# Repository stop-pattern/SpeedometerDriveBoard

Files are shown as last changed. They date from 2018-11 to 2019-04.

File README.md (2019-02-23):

SpeedometerDriveBoard
===

## table of contents
- [日本語版](#Japanese)[](\readme_jp.md)
- [English](#English)
  - [Requirement](#Requirement)
  - [Installation](#Installation)
    - [board](#board)
    - [code](#code)
  - [Licence](#Licence)
  - [Author](#Author)

---

## Japanese
このリポジトリ内の創造物は、[BIDSid_SerCon](https://github.com/TetsuOtter/BIDSid_SerCon/)を使用する前提で設計されています。  
基板は5000円以下/枚で生産できますが、現在製造中につき値段の詳細については分かりかねます。(分かり次第追記予定  
日本語版は工事中ですのでお手数ですが下記英語版をご覧いただきますよう...

---

## English
This Repository is designed on the premise of using [__BIDSid_SerCon__](https://github.com/TetsuOtter/BIDSid_SerCon/).  
This is for original board on esp32 that created and designed by stop_pattern.  
This board can be produced at less than 5000JPY / piece.  
But do not know details of the price because it is currently under manufacturing.  
(Scheduled to be appended as soon as it is known)  

### Requirement
using:
[BIDSid_SerCon](https://github.com/TetsuOtter/BIDSid_SerCon/).  
supported:
[Bve trainsim](http://bvets.net/)  
support __Bve trainsim__, but the supported version _5.7_ or newer.  
__Bve trainsim__ spported only _Windows Vista_ or _newer_, so support only _Windows Vista_ or _newer_ too.  

### Usage
Change the settings, in the firmware source code according to your own environment.  
write firmware to esp32 through __Arduino IDE__.  

### Installation
#### board:
1. Request PCB service company to manufacture circuit board.  
2. Test manufactured board and Implemented parts.  
#### code:
1. write firmware to esp32 through __Arduino IDE__.  
2. setup [__Bve trainsim__](http://bvets.net/en/download/)  
3. Introduce [__BIDSid_SerCon__](https://github.com/TetsuOtter/BIDSid_SerCon/) into __Bve trainsim__.  

### Licence
board:
[GPLv3](https://www.gnu.org/licenses/gpl-3.0.html)  
code:
[MIT](https://github.com/tcnksm/tool/blob/master/LICENCE)  

### Author
[stop_pattern](https://github.com/stop-pattern)

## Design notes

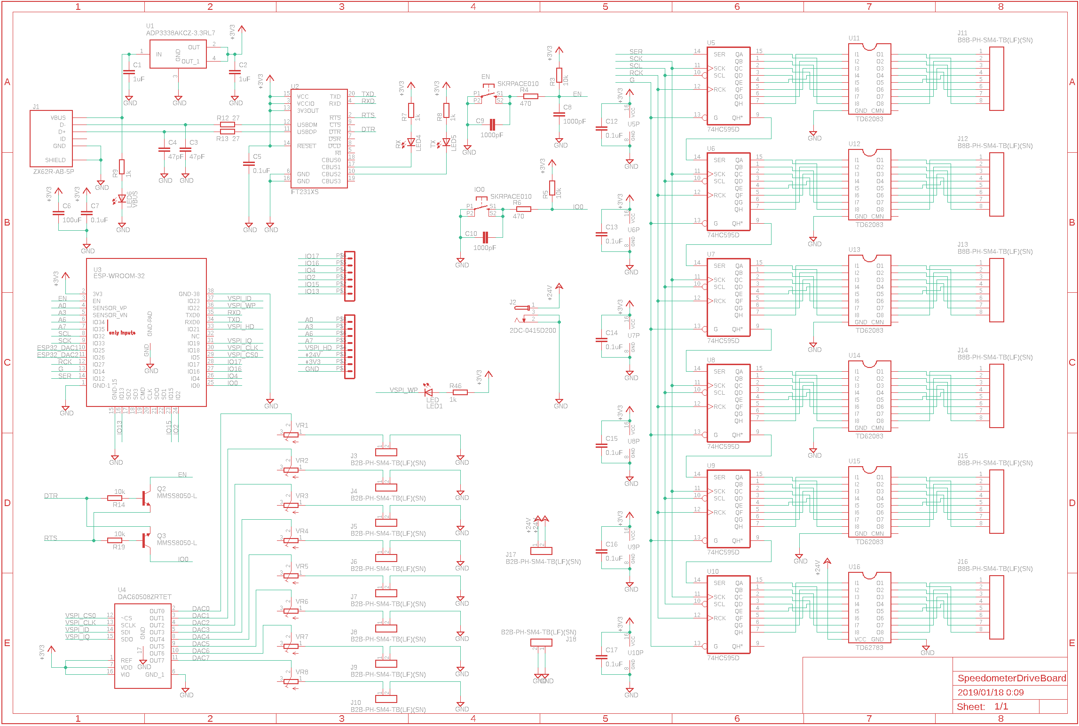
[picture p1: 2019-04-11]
board/sch.png

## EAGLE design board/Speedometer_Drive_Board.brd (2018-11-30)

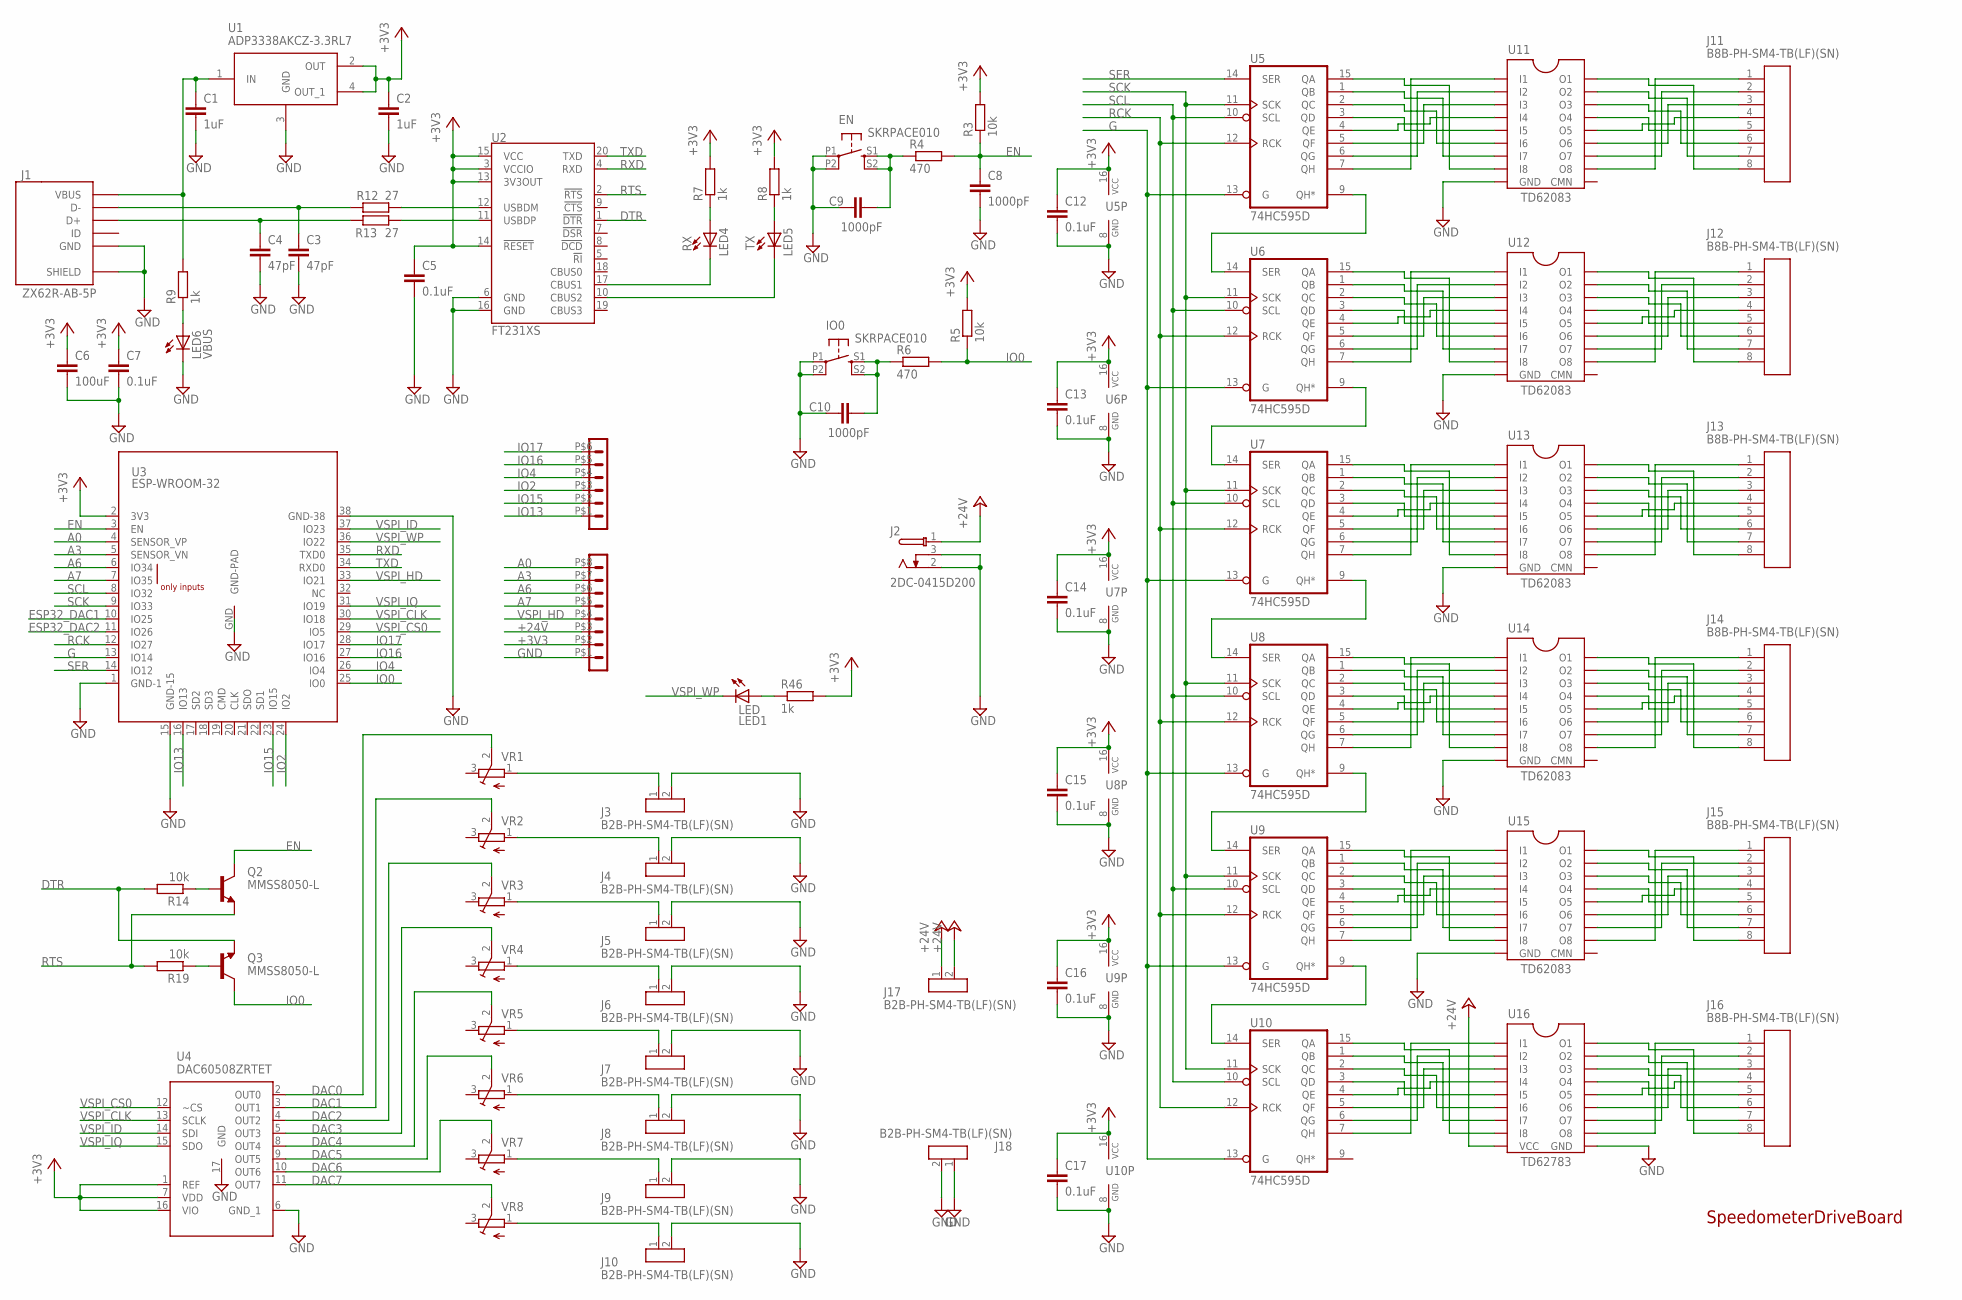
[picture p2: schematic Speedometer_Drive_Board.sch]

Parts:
C1, C2: 1uF; C0603
C3, C4: 47pF; C0603
C5, C7, C12, C13, C14, C15, C16, C17: 0.1uF; C0603
C6: 100uF; C1210
C8, C9, C10: 1000pF; C0603
EN: SKRPACE010
IO0: SKRPACE010
J1: ZX62R-AB-5P; ZX62R-B-5PA
J2: 2DC-0415D200
J3, J4, J5, J6, J7, J8, J9, J10, J17, J18: B2B-PH-SM4-TB(LF)(SN); SAMACSYS_PARTS_B2B-PH-SM4-TB
J11, J12, J13, J14, J15, J16: B8B-PH-SM4-TB(LF)(SN); SAMACSYS_PARTS_B8B-PH-SM4-TB
J19: PIN_HEADER_MALE_1X06_06P
J20: PIN_HEADER_MALE_1X08_08P
LED: LED1; CHIPLED_0603
LED4: RX; CHIPLED_0603
LED5: TX; CHIPLED_0603
LED6: VBUS; CHIPLED_0603
Q2, Q3: MMSS8050-L; SOT23
R3, R5, R14, R19: 10k; R0603
R4, R6: 470; R0603
R7, R8, R9, R46: 1k; R0603
R12, R13: 27; R0603
U1: ADP3338AKCZ-3.3RL7; SOT230P700X180-4N
U2: FT231XS; SSOP20_L
U3: ESP-WROOM-32
U4: DAC60508ZRTET; SAMACSYS_PARTS_QFN50P300X300X80-17N
U5, U6, U7, U8, U9, U10: 74HC595D; SO16
U11, U12, U13, U14, U15: TD62083; SO18
U16: TD62783; SO18
VR1, VR2, VR3, VR4, VR5, VR6, VR7, VR8: TRIM_EU-SM-42/43W; SM-42/43W

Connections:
+3V3: C2.1, C5.1, C6.1, C7.1, C12.1, C13.1, C14.1, C15.1, C16.1, C17.1, J20.P$2 (2), R3.2, R5.2, R7.2, R8.2, R46.2, U1.2 (OUT), U1.4 (OUT_1), U2.3 (VCCIO), U2.13 (3V3OUT), U2.14 (!RESET), U2.15 (VCC), U3.2 (3V3), U4.1 (REF), U4.7 (VDD), U4.16 (VIO), U5.16 (VCC), U6.16 (VCC), U7.16 (VCC), U8.16 (VCC), U9.16 (VCC), U10.16 (VCC)
+24V: J2.1, J17.1, J17.2, J20.P$3 (3), U16.9 (VCC)
A0: J20.P$8 (8), U3.4 (SENSOR_VP)
A3: J20.P$7 (7), U3.5 (SENSOR_VN)
A6: J20.P$6 (6), U3.6 (IO34)
A7: J20.P$5 (5), U3.7 (IO35)
D2_N1: R12.2, U2.12 (USBDM)
D2_P1: R13.2, U2.11 (USBDP)
DAC0: U4.2 (OUT0), VR1.2 (S)
DAC1: U4.3 (OUT1), VR2.2 (S)
DAC2: U4.4 (OUT2), VR3.2 (S)
DAC3: U4.5 (OUT3), VR4.2 (S)
DAC4: U4.8 (OUT4), VR5.2 (S)
DAC5: U4.9 (OUT5), VR6.2 (S)
DAC6: U4.10 (OUT6), VR7.2 (S)
DAC7: U4.11 (OUT7), VR8.2 (S)
DTR: Q3.E, R14.2, U2.1 (!DTR)
D_N1: C3.1, J1.D-, R12.1
D_P1: C4.1, J1.D+, R13.1
EN: C8.1, Q2.C, R3.1, R4.2, U3.3 (EN)
ESP32_DAC1: U3.10 (IO25)
ESP32_DAC2: U3.11 (IO26)
G: U3.13 (IO14), U5.13 (G), U6.13 (G), U7.13 (G), U8.13 (G), U9.13 (G), U10.13 (G)
GND: C1.2, C2.2, C3.2, C4.2, C5.2, C6.2, C7.2, C8.2, C9.1, C10.1, C12.2, C13.2, C14.2, C15.2, C16.2, C17.2, EN.P1, EN.P2 (P1), IO0.P1, IO0.P2 (P1), J1.GND, J1.SHIELD@1 (SHIELD), J1.SHIELD@2 (SHIELD), J1.SHIELD@3 (SHIELD), J1.SHIELD@4 (SHIELD), J2.2, J2.3, J3.2, J4.2, J5.2, J6.2, J7.2, J8.2, J9.2, J10.2, J18.1, J18.2, J20.P$1 (1), LED6.C, U1.3 (GND), U2.6 (GND), U2.16 (GND), U3.1 (GND-1), U3.15 (GND-15), U3.38 (GND-38), U3.GND (GND-PAD), U4.6 (GND_1), U4.17 (GND), U5.8 (GND), U6.8 (GND), U7.8 (GND), U8.8 (GND), U9.8 (GND), U10.8 (GND), U11.9 (GND), U12.9 (GND), U13.9 (GND), U14.9 (GND), U15.9 (GND), U16.10 (GND)
IO0: Q3.C, R5.1, R6.2, U3.25 (IO0)
IO2: J19.P$3 (3), U3.24 (IO2)
IO4: J19.P$4 (4), U3.26 (IO4)
IO13: J19.P$1 (1), U3.16 (IO13)
IO15: J19.P$2 (2), U3.23 (IO15)
IO16: J19.P$5 (5), U3.27 (IO16)
IO17: J19.P$6 (6), U3.28 (IO17)
unnamed: U5.9 (QH*), U6.14 (SER)
unnamed: U6.9 (QH*), U7.14 (SER)
unnamed: U7.9 (QH*), U8.14 (SER)
unnamed: U5.7 (QH), U11.1 (I1)
unnamed: U5.6 (QG), U11.2 (I2)
unnamed: U5.5 (QF), U11.3 (I3)
unnamed: LED.A, R46.1
unnamed: U5.4 (QE), U11.4 (I4)
unnamed: U5.3 (QD), U11.5 (I5)
unnamed: U5.2 (QC), U11.6 (I6)
unnamed: U5.1 (QB), U11.7 (I7)
unnamed: U5.15 (QA), U11.8 (I8)
unnamed: J11.1 (S1), U11.11 (O8)
unnamed: J11.2 (S2), U11.12 (O7)
unnamed: J11.3 (S3), U11.13 (O6)
unnamed: J11.4 (S4), U11.14 (O5)
unnamed: J11.5 (S5), U11.15 (O4)
unnamed: J11.6 (S6), U11.16 (O3)
unnamed: J11.7 (S7), U11.17 (O2)
unnamed: J11.8 (S8), U11.18 (O1)
unnamed: U7.7 (QH), U13.1 (I1)
unnamed: U6.7 (QH), U12.1 (I1)
unnamed: U6.6 (QG), U12.2 (I2)
unnamed: U6.5 (QF), U12.3 (I3)
unnamed: U6.4 (QE), U12.4 (I4)
unnamed: U6.3 (QD), U12.5 (I5)
unnamed: U6.2 (QC), U12.6 (I6)
unnamed: U6.1 (QB), U12.7 (I7)
unnamed: U6.15 (QA), U12.8 (I8)
unnamed: J12.1 (S1), U12.11 (O8)
unnamed: J12.2 (S2), U12.12 (O7)
unnamed: J12.3 (S3), U12.13 (O6)
unnamed: J12.4 (S4), U12.14 (O5)
unnamed: J12.5 (S5), U12.15 (O4)
unnamed: J12.6 (S6), U12.16 (O3)
unnamed: J12.7 (S7), U12.17 (O2)
unnamed: J12.8 (S8), U12.18 (O1)
unnamed: U7.6 (QG), U13.2 (I2)
unnamed: U7.5 (QF), U13.3 (I3)
unnamed: U7.4 (QE), U13.4 (I4)
unnamed: U7.3 (QD), U13.5 (I5)
unnamed: U7.2 (QC), U13.6 (I6)
unnamed: U7.1 (QB), U13.7 (I7)
unnamed: U7.15 (QA), U13.8 (I8)
unnamed: J13.1 (S1), U13.11 (O8)
unnamed: J13.2 (S2), U13.12 (O7)
unnamed: J13.3 (S3), U13.13 (O6)
unnamed: J13.4 (S4), U13.14 (O5)
unnamed: J13.5 (S5), U13.15 (O4)
unnamed: J13.6 (S6), U13.16 (O3)
unnamed: J13.7 (S7), U13.17 (O2)
unnamed: J13.8 (S8), U13.18 (O1)
unnamed: U8.7 (QH), U14.1 (I1)
unnamed: U8.6 (QG), U14.2 (I2)
unnamed: U8.5 (QF), U14.3 (I3)
unnamed: U8.4 (QE), U14.4 (I4)
unnamed: U8.3 (QD), U14.5 (I5)
unnamed: U8.2 (QC), U14.6 (I6)
unnamed: U8.1 (QB), U14.7 (I7)
unnamed: U8.15 (QA), U14.8 (I8)
unnamed: J14.1 (S1), U14.11 (O8)
unnamed: J14.2 (S2), U14.12 (O7)
unnamed: J14.3 (S3), U14.13 (O6)
unnamed: J14.4 (S4), U14.14 (O5)
unnamed: J14.5 (S5), U14.15 (O4)
unnamed: J14.6 (S6), U14.16 (O3)
unnamed: J14.7 (S7), U14.17 (O2)
unnamed: J14.8 (S8), U14.18 (O1)
unnamed: U9.7 (QH), U15.1 (I1)
unnamed: U9.6 (QG), U15.2 (I2)
unnamed: U9.5 (QF), U15.3 (I3)
unnamed: U9.4 (QE), U15.4 (I4)
unnamed: U9.3 (QD), U15.5 (I5)
unnamed: U9.2 (QC), U15.6 (I6)
unnamed: U8.9 (QH*), U9.14 (SER)
unnamed: U9.1 (QB), U15.7 (I7)
unnamed: U9.15 (QA), U15.8 (I8)
unnamed: J15.1 (S1), U15.11 (O8)
unnamed: J15.2 (S2), U15.12 (O7)
unnamed: J15.3 (S3), U15.13 (O6)
unnamed: J15.4 (S4), U15.14 (O5)
unnamed: J15.5 (S5), U15.15 (O4)
unnamed: J15.6 (S6), U15.16 (O3)
unnamed: J15.7 (S7), U15.17 (O2)
unnamed: J15.8 (S8), U15.18 (O1)
unnamed: U10.7 (QH), U16.1 (I1)
unnamed: U10.6 (QG), U16.2 (I2)
unnamed: U10.5 (QF), U16.3 (I3)
unnamed: U10.4 (QE), U16.4 (I4)
unnamed: U10.3 (QD), U16.5 (I5)
unnamed: U10.2 (QC), U16.6 (I6)
unnamed: U10.1 (QB), U16.7 (I7)
unnamed: U9.9 (QH*), U10.14 (SER)
unnamed: U10.15 (QA), U16.8 (I8)
unnamed: J16.1 (S1), U16.11 (O8)
unnamed: J16.2 (S2), U16.12 (O7)
unnamed: J16.3 (S3), U16.13 (O6)
unnamed: J16.4 (S4), U16.14 (O5)
unnamed: J16.5 (S5), U16.15 (O4)
unnamed: J16.6 (S6), U16.16 (O3)
unnamed: J16.7 (S7), U16.17 (O2)
unnamed: J16.8 (S8), U16.18 (O1)
unnamed: J10.1, VR8.1 (A)
unnamed: J9.1, VR7.1 (A)
unnamed: J8.1, VR6.1 (A)
unnamed: J7.1, VR5.1 (A)
unnamed: J3.1, VR1.1 (A)
unnamed: J4.1, VR2.1 (A)
unnamed: J5.1, VR3.1 (A)
unnamed: J6.1, VR4.1 (A)
unnamed: C9.2, EN.S1 (S), EN.S2 (S1), R4.1
unnamed: C10.2, IO0.S1 (S), IO0.S2 (S1), R6.1
unnamed: LED4.C, U2.17 (CBUS1)
unnamed: LED5.C, U2.10 (CBUS2)
unnamed: LED4.A, R7.1
unnamed: LED5.A, R8.1
unnamed: LED6.A, R9.1
unnamed: Q2.B, R14.1
unnamed: Q3.B, R19.1
RCK: U3.12 (IO27), U5.12 (RCK), U6.12 (RCK), U7.12 (RCK), U8.12 (RCK), U9.12 (RCK), U10.12 (RCK)
RTS: Q2.E, R19.2, U2.2 (!RTS)
RXD: U2.4 (RXD), U3.35 (TXD0)
SCK: U3.9 (IO33), U5.11 (SCK), U6.11 (SCK), U7.11 (SCK), U8.11 (SCK), U9.11 (SCK), U10.11 (SCK)
SCL: U3.8 (IO32), U5.10 (SCL), U6.10 (SCL), U7.10 (SCL), U8.10 (SCL), U9.10 (SCL), U10.10 (SCL)
SER: U3.14 (IO12), U5.14 (SER)
TXD: U2.20 (TXD), U3.34 (RXD0)
VBUS3: C1.1, J1.VCC (VBUS), R9.2, U1.1 (IN)
VSPI_CLK: U3.30 (IO18), U4.13 (SCLK)
VSPI_CS0: U3.29 (IO5), U4.12 (~CS)
VSPI_HD: J20.P$4 (4), U3.33 (IO21)
VSPI_ID: U3.37 (IO23), U4.14 (SDI)
VSPI_IQ: U3.31 (IO19), U4.15 (SDO)
VSPI_WP: LED.C, U3.36 (IO22)

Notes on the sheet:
SpeedometerDriveBoard

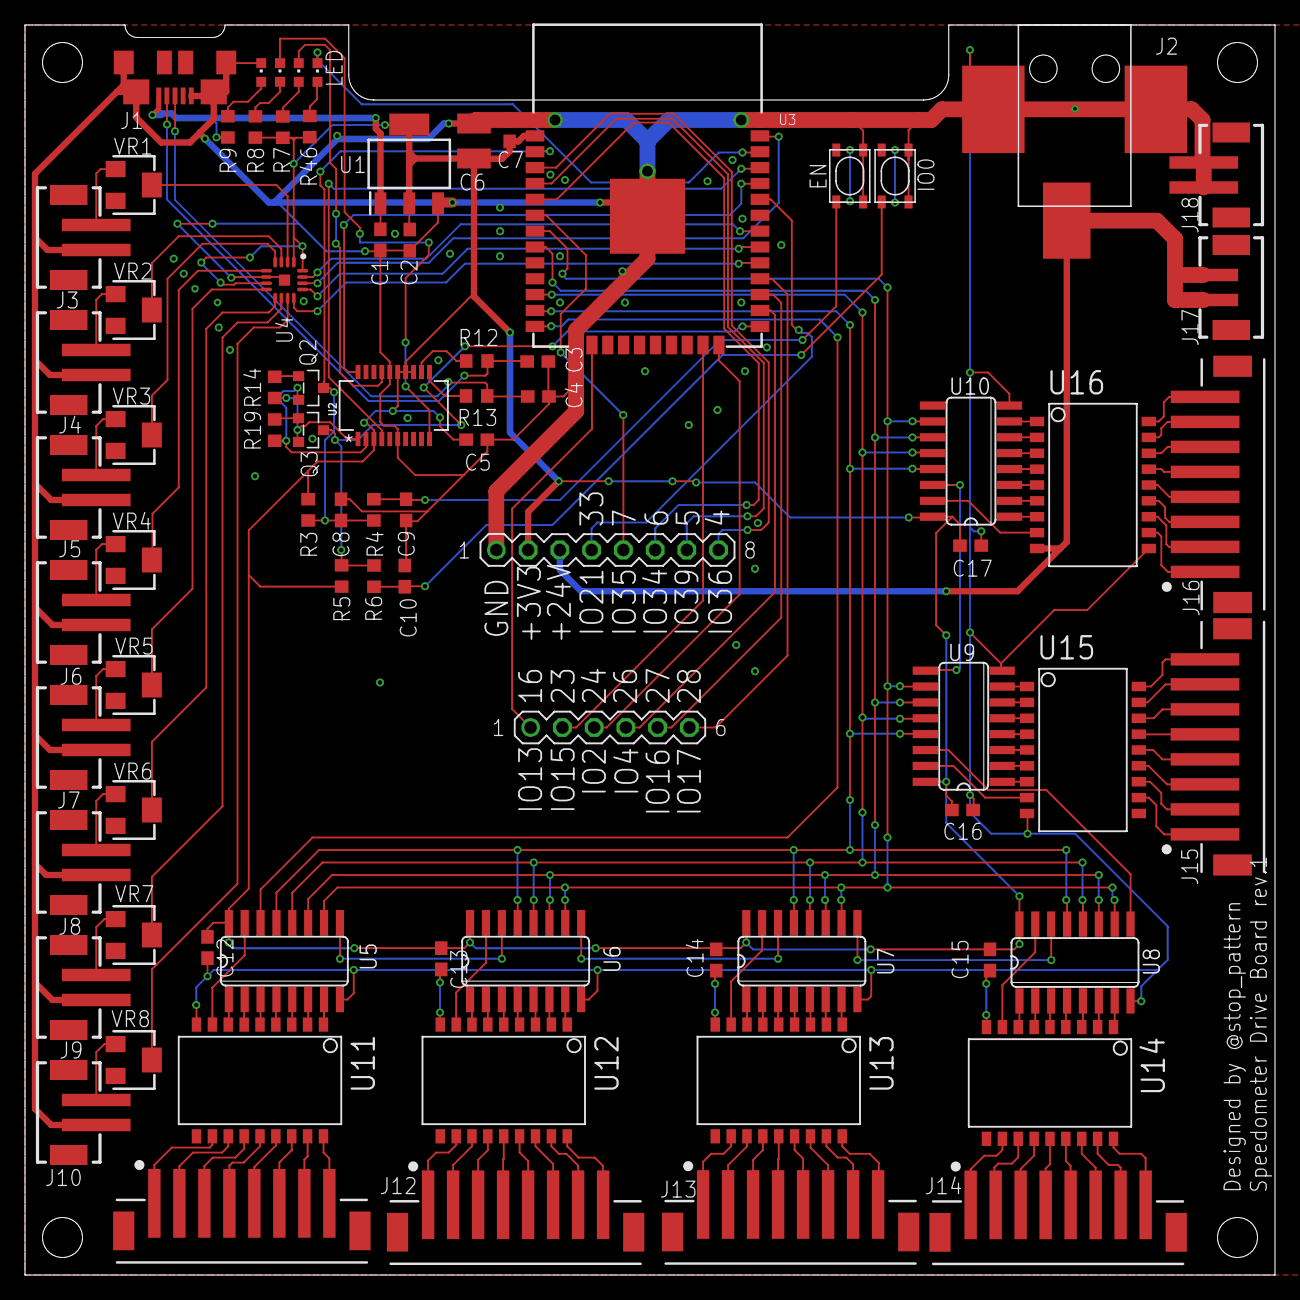
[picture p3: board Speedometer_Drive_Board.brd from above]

Board: 2 copper layers, 100.0 x 100.0 mm, 80 parts (0 on the bottom side), 162 nets.

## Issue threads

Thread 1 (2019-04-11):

want to remake board

stop-pattern, 2019-04-11:
要修正点
- 再配線/基板サイズ縮小
- DACバイパスコンデンサ追加([データシート](http://www.ti.com/lit/ds/symlink/dac80508.pdf)参照)
- BOM添付
- 足とPADのサイズすり合わせ

stop-pattern, 2019-04-11:
基板はrepo分けたほうがいいかもしれない

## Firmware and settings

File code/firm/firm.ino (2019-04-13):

#include "define.h"
#include "BIDS.h"
#include <SPI.h>

int VersionNum = 100;


/*----------variants---------*/
extern double Speed;
extern double ORP;
extern int indicator[25];
extern int R, G, notice, P, X, BL;
extern int bell;
extern int L15, L60, ATS;
extern int cnt;
extern bool shiftregister[50];
extern int reg;


bool light_on[] = {
  1, 1, 1, 1, 1, 1, 1, 1, 1, 1,
  1, 1, 1, 1, 1, 1, 1, 1, 1, 1,
  1, 1, 1, 1, 1, 1, 1, 1, 1, 1,
  1, 1, 1, 1, 1, 1, 1, 1, 1, 1,
  1, 1, 1, 1, 1, 1, 1, 1,
};
bool light_off[] = {
  0, 0, 0, 0, 0, 0, 0, 0, 0, 0,
  0, 0, 0, 0, 0, 0, 0, 0, 0, 0,
  0, 0, 0, 0, 0, 0, 0, 0, 0, 0,
  0, 0, 0, 0, 0, 0, 0, 0, 0, 0,
  0, 0, 0, 0, 0, 0, 0, 0,
};


void setup() {
  pinMode(IO0, INPUT);
  pinMode(SW, INPUT);
  pinMode(LED, OUTPUT);
  pinMode(DAC1, OUTPUT);
  pinMode(DAC2, OUTPUT);

  pinMode(SER, OUTPUT);
  pinMode(RCK, OUTPUT);
  pinMode(SCK, OUTPUT);
  pinMode(OE, OUTPUT);
  pinMode(SCL, OUTPUT);

  pinMode(MOSI, OUTPUT);
  pinMode(MISO, OUTPUT);
  pinMode(SCLK, OUTPUT);
  pinMode(SS, OUTPUT);

  attachInterrupt(SW, interrupt, CHANGE); //スイッチ割込み

  cnt = 0;

  digitalWrite(LED, HIGH);
  digitalWrite(SS, HIGH);

  Serial.begin(115200);
  while (!Serial);
  VersionNum = BIDS::VersionCheck(VersionNum);

  SPI.beginTransaction(SPISettings(50000000, MSBFIRST, SPI_MODE1));
  SPI.begin();
  SPI.transfer(0b000000101111111100000000);

  digitalWrite(LED, HIGH);

  digitalWrite(OE, LOW);
  digitalWrite(SCL, HIGH);
}

void loop() {

  GetData();

  SetData();

  if (isSW) {
    if (analogRead(SW) == HIGH) {
      BIDS::DataGet("K", "P", 0);
    } else  {
      BIDS::DataGet("K", "R", 0);
    }
    isSW = false;
  }

  delay(1);
}

//スイッチ割込み
void interrupt(void) {
  isSW = true;
}

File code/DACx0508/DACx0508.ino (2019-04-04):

#include <SPI.h>

#define MOSI   (12)
#define MISO   (27)
#define CLOCK  (33)
#define SS     (14)

#define SPI_CLOCK_SPEED 1000000
SPIClass * vspi = NULL;

int SPIsend(int senddata) {

  //通信中
  digitalWrite(SS, LOW);
  vspi->transfer(senddata);
  digitalWrite(SS, HIGH);

  //通信終了
  //vspi->endTransaction();
}

void setup()
{
  //SPIのインスタンス作成
  vspi = new SPIClass(VSPI);
  vspi->begin();

  //pin初期化
  pinMode(SS, OUTPUT);

  //シリアル開始
  Serial.begin(19200);
  while (!Serial); //接続待機

  //通信開始
  vspi->beginTransaction(SPISettings(SPI_CLOCK_SPEED, MSBFIRST, SPI_MODE0));

  //DACx050x
  DACx050x :DAC;
}

void loop() {
  SPIsend(0b000010001111111111111111);
  SPIsend(0b000010011111111111111111);
  delay(1000);
}

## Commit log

2018-11-30 [add] add Schematic & Board
    [Speedometer_Drive_Board.brd, Speedometer_Drive_Board.sch]
2019-01-17 [clean] フォルダ整理
    [Speedometer_Drive_Board.brd, Speedometer_Drive_Board.sch]
2019-01-17 [add] コード追加
    基板用ファームコード追加
    [Speedometer_Drive_Board.brd, Speedometer_Drive_Board.sch]
2019-01-18 [add] コードを追加
    firm/ 基板ファーム (途中）
    firm_test/ 速度計Lチカ （動かない）
    test_LED/ 基板上Lチカ （完成）
2019-01-18 [fix] 基板Lチカコードのミスを修正
2019-02-23 動いたやつ
2019-02-24 デモ仕様
2019-02-24 bell改良&通信回数削減
2019-04-04 [change] 色々変えたのでなに変えたか覚えてない
    ボタン操作で割込みから警笛ならせるようにはした
    通信回数がどうしても多いのでプラグイン書いてpanelを一か所潰してその値を丸ごと送受信するようにしたいかなぁと模索中
    次までにこれよりいい案がなければ多分これで実装する
2019-04-11 [update] update firmware
    ifdef _NEW_ で[board_PI](https://github.com/stop-pattern/board_PI)に対応
    なお旧版はelseで使用可能
2019-04-13 [fix] fix transmission bug
    modified to change the state of chip select pin
    [Source.cpp, firm.ino]
